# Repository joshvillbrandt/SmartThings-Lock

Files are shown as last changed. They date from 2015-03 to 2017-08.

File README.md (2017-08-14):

# SmartThings Lock

An Internet of Things door lock using an Arduino and the SmartThings platform.

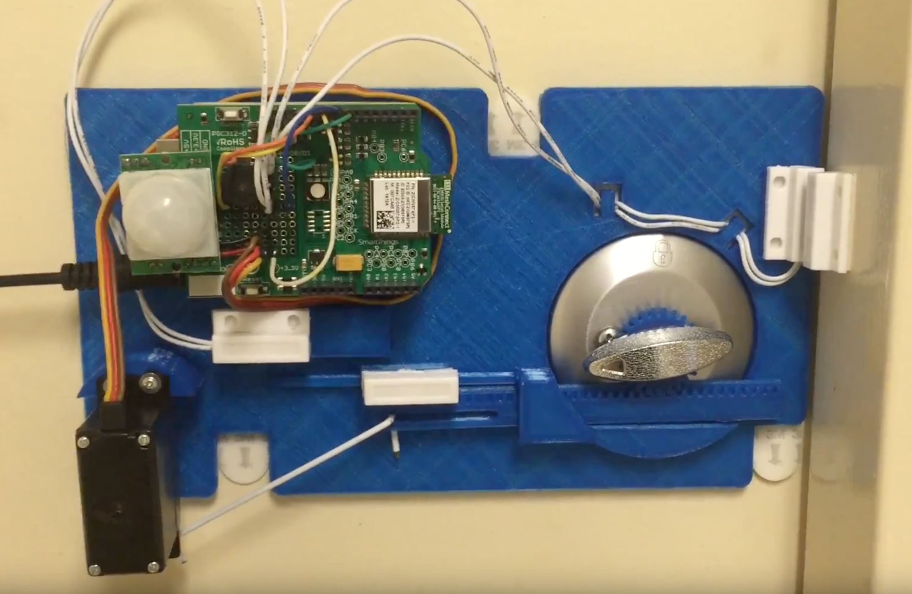
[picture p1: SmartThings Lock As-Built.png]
as-built screenshot


## Summary

This projects creates a network-connected door lock. The device uses two reed switches to report the open/closed status of the door and the locked/unlocked status of the lock. The door's lock may be engaged and disengaged via a servo. The locking mechanism works without inhibiting the door to be locked or unlocked via standard methods (using a key or by turning the thumb-turn.)

An Arduino Uno with a SmartThings ThingShield connects to the SmartThings hub with the help of the [ST_Anything](https://github.com/DanielOgorchock/ST_Anything) Arduino library.

## Bill of Materials

| Qty. | Item | Link |
| --- | --- | --- |
| 1 | Arduino Uno | http://www.amazon.com/IEIK-Board-ATmega328P-Cable-Arduino/dp/B00P2FX9WY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 |
| 1 | Arduino DC Power Adapter | http://www.amazon.com/Power-Adapter-Arduino-2-Flat-Pin-100CM/dp/B00CP1QLSC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 |
| 1 | SmartThings ThingShield | https://shop.smartthings.com/#!/products/smartthings-shield-arduino |
| 1 | Adafruit PIR Motion Sensor | http://www.amazon.com/gp/product/B00JOZTAC6/ref=oh_aui_detailpage_o00_s00?ie=UTF8&psc=1 |
| 2 | Magnetic Reed Switches | http://www.amazon.com/gp/product/B00HR8CT8E/ref=oh_aui_detailpage_o00_s00?ie=UTF8&psc=1 |
| 1 | Standard Servo | http://www.amazon.com/Hitec-31311S-HS-311-Standard-Universal/dp/B0006O3WVE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 |
| 1 | Piezo-electric buzzer | http://www.amazon.com/Terminals-Electronic-Continuous-Sound-Buzzer/dp/B00B0Q4KKO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 |
| 1 | 3D Printed SmartThings Lock Set | n/a |
| 1 | Wire Close Hanger | n/a |

## Electrical Schematic

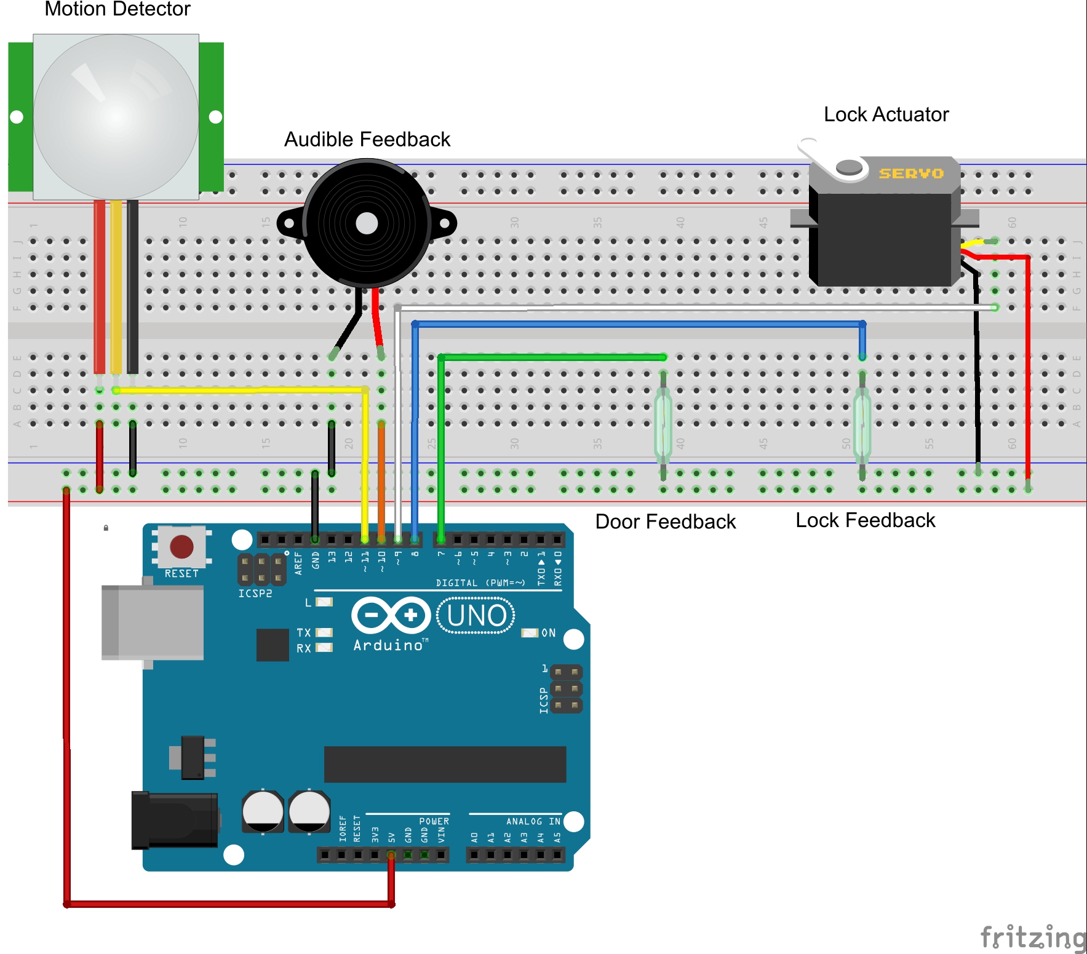
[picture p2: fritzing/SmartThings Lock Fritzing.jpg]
electrical screenshot


## Digital Model

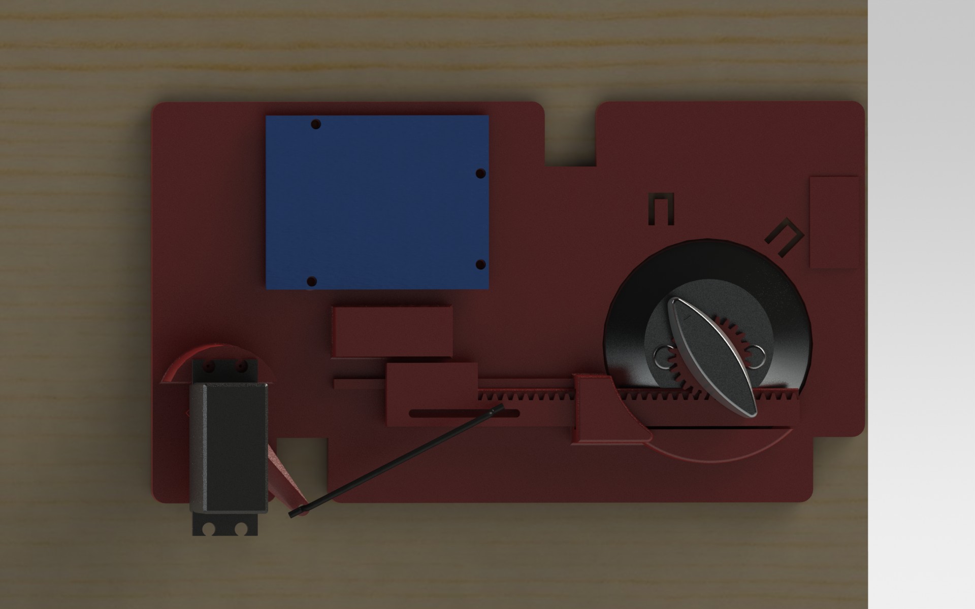
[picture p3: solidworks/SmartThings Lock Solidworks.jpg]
mechanical screenshot


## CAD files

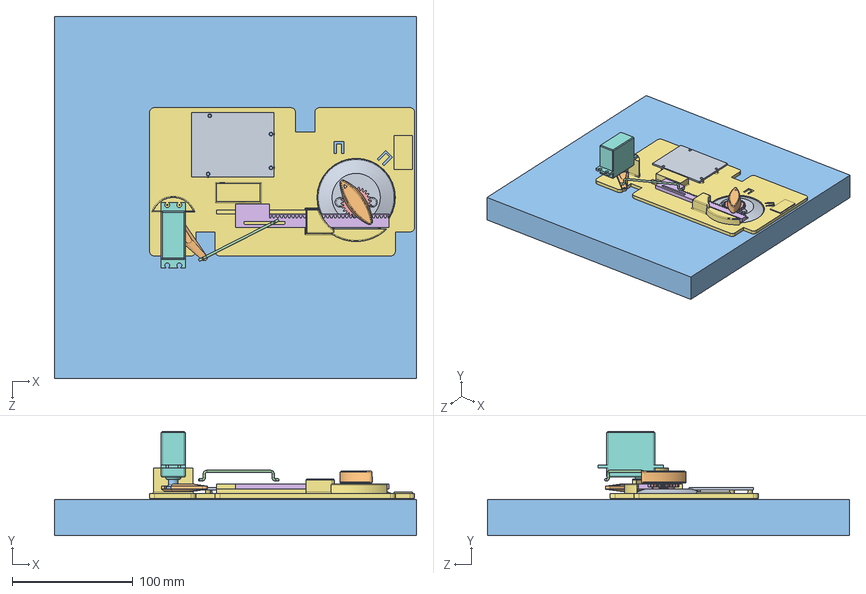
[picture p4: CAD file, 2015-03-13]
solidworks/SmartThings Lock.SLDASM
300.0 x 86.5 x 300.0 mm
Lock Body
Lock Thumb Turn
Door
Control Link
Control Gear
Control Runner
Base
Standard Servo
Arduino PCB
Control Arm Extender
Control Arm

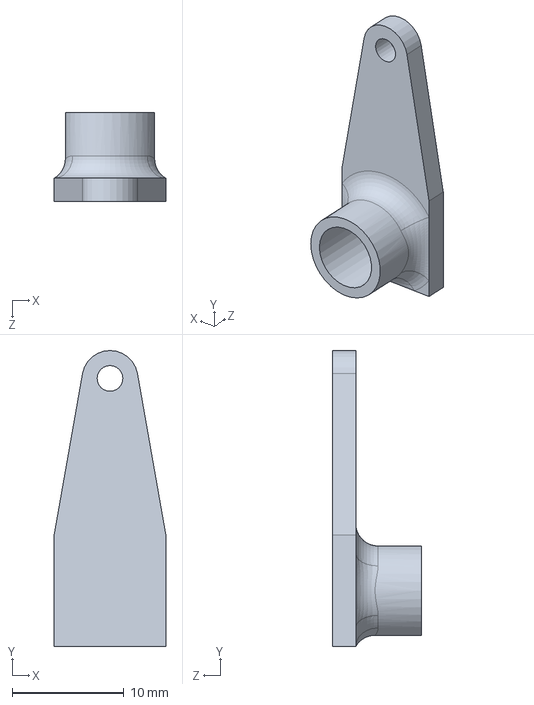
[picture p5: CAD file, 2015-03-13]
solidworks/Control Arm.SLDPRT
10.0 x 26.5 x 8.00 mm

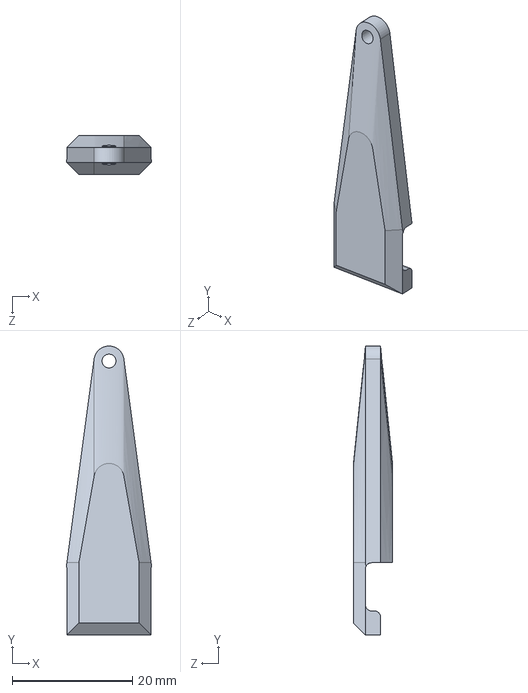
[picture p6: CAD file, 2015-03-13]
solidworks/Control Arm Extender.SLDPRT
14.2 x 48.0 x 6.50 mm

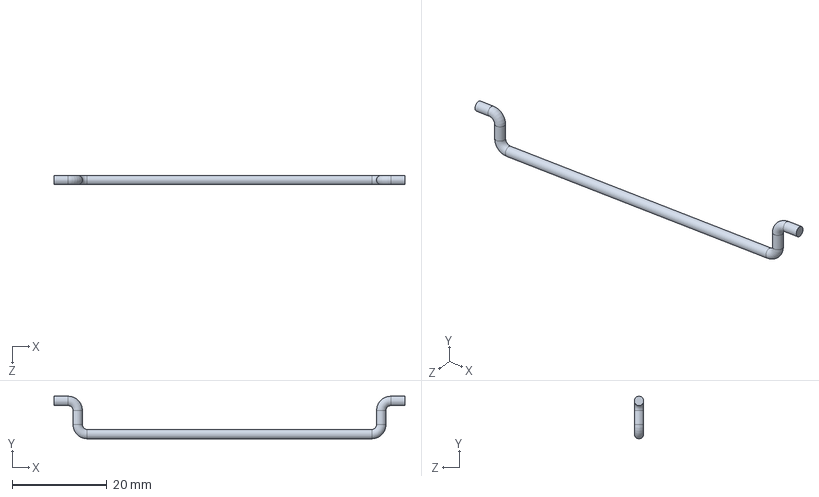
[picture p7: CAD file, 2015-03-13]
solidworks/Control Link.SLDPRT
74.0 x 9.00 x 2.00 mm

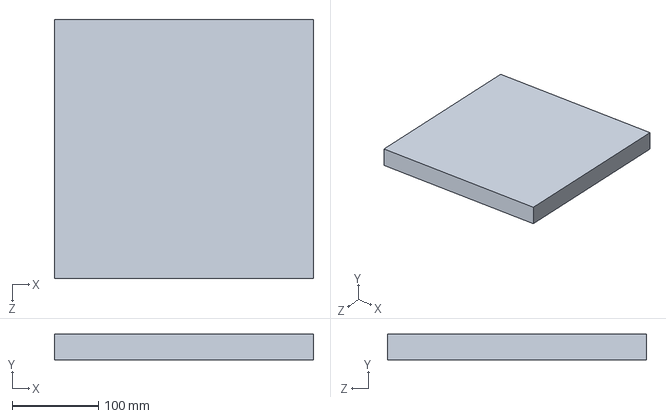
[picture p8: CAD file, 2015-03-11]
solidworks/Door.SLDPRT
300.0 x 30.0 x 300.0 mm

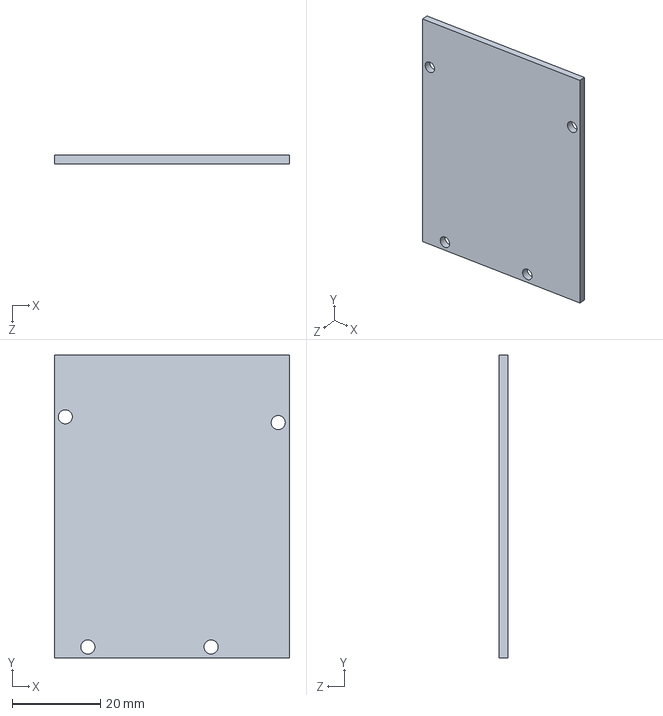
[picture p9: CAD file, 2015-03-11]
solidworks/Arduino PCB.SLDPRT
53.3 x 68.6 x 2.00 mm

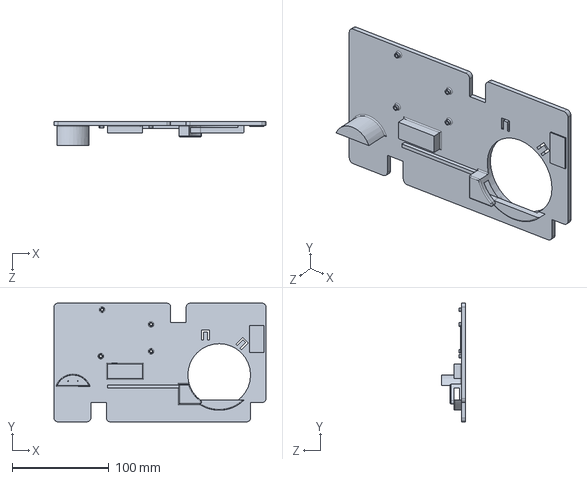
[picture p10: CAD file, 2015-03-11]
solidworks/Base.SLDPRT
219.7 x 123.0 x 25.0 mm

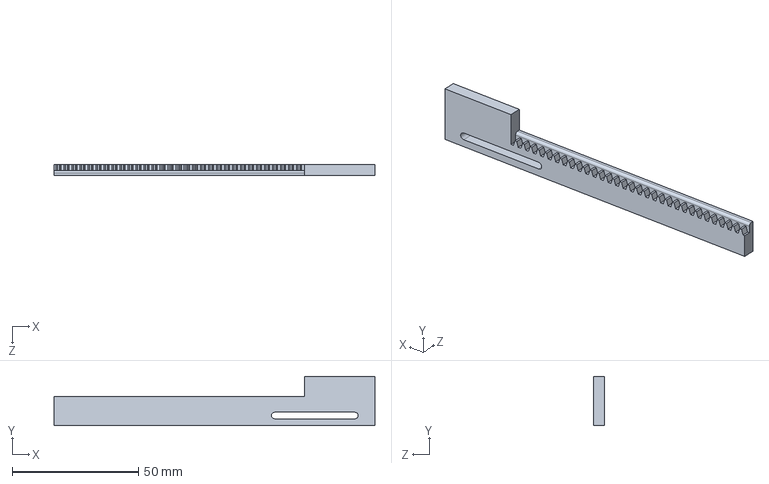
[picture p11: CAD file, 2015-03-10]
solidworks/Control Runner.SLDPRT
127.2 x 19.5 x 4.50 mm

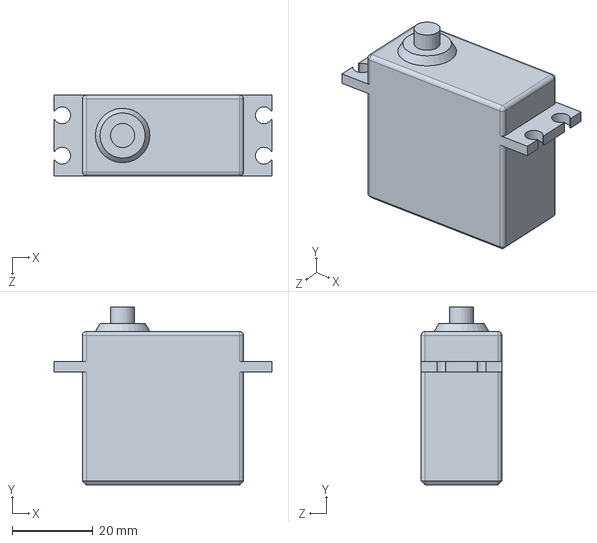
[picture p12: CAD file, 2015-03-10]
solidworks/Standard Servo.SLDPRT
54.0 x 44.0 x 20.0 mm

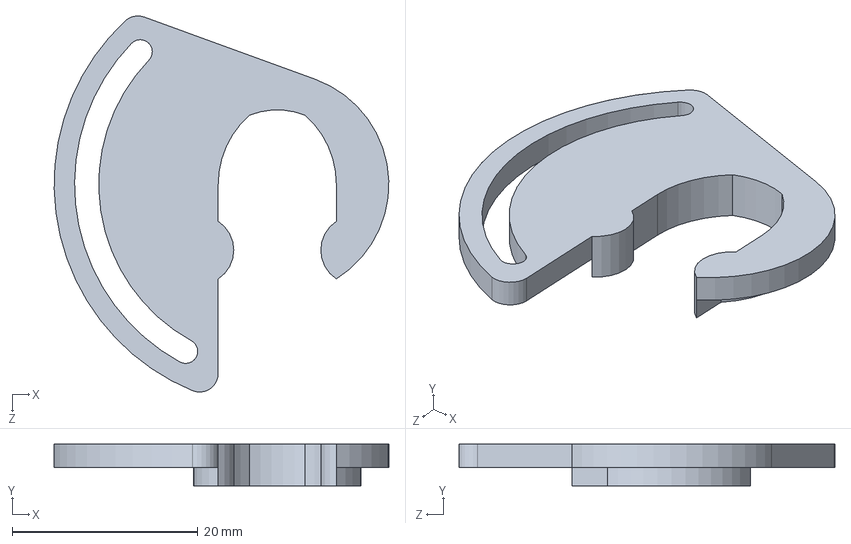
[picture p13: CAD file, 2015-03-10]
solidworks/Control Adapter.SLDPRT
36.0 x 4.50 x 40.4 mm

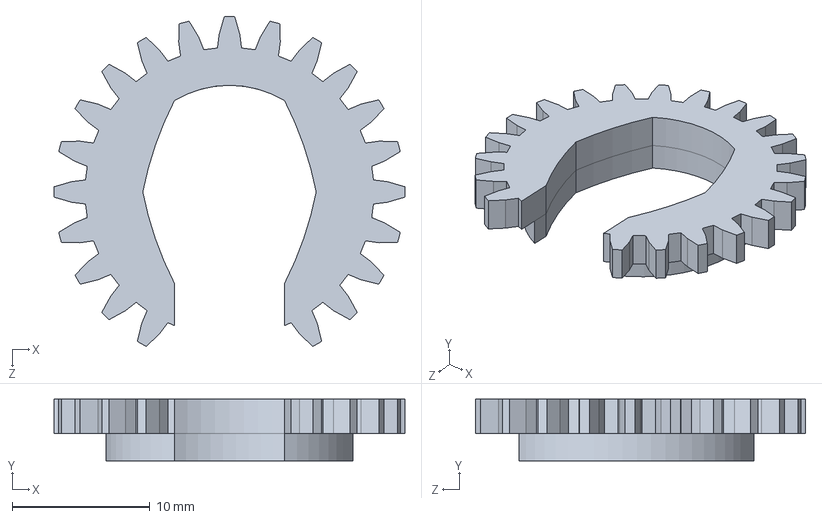
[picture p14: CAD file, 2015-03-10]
solidworks/Control Gear.SLDPRT
25.5 x 4.50 x 24.0 mm

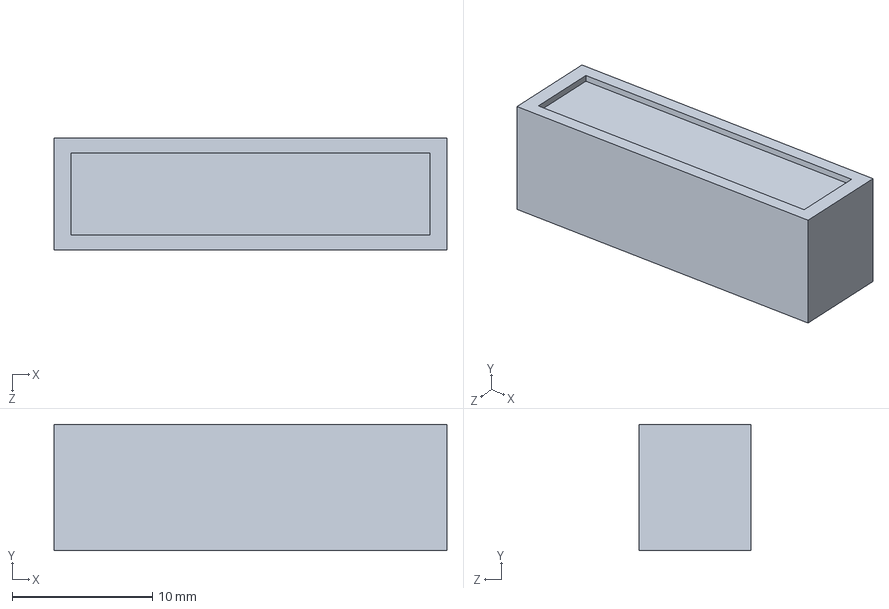
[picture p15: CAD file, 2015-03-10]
solidworks/Clipped Magnet.SLDPRT
28.0 x 9.00 x 8.00 mm

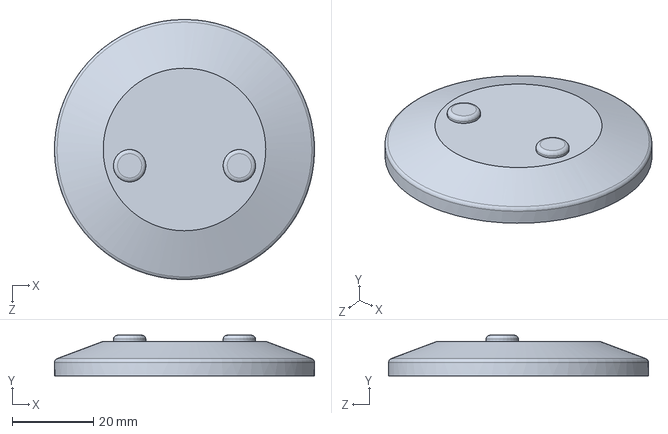
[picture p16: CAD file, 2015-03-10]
solidworks/Lock Body.SLDPRT
64.0 x 10.0 x 64.0 mm

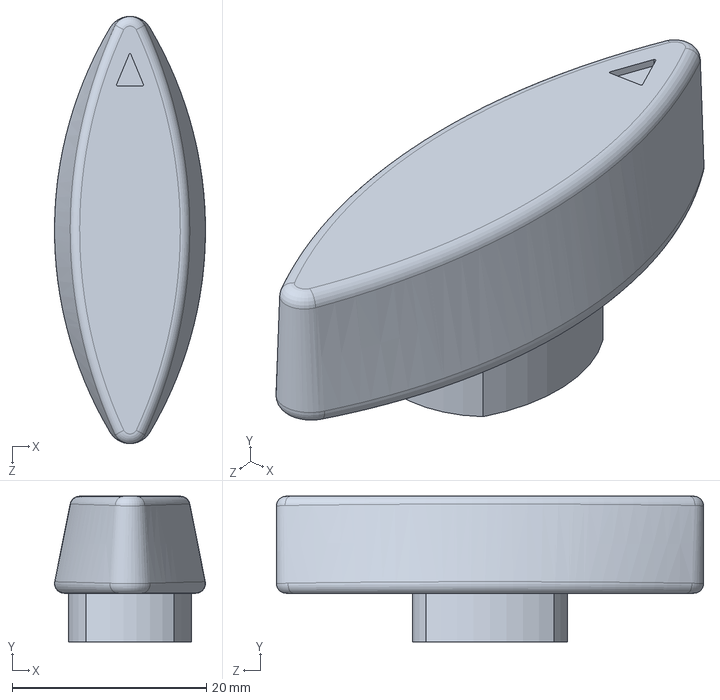
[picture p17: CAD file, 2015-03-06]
solidworks/Lock Thumb Turn.SLDPRT
15.6 x 15.0 x 44.0 mm

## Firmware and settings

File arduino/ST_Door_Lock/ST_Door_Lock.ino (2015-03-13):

//******************************************************************************************
//  File: ST_Door_Lock.ino
//  Authors: Josh Villbrandt
//
//  Change History:
//
//    Date        Who              What
//    ----        ---              ----
//    2015-03-13  Josh Villbrandt  Inital script]
//
//******************************************************************************************

//******************************************************************************************
// SmartThings Library for Arduino Shield
//******************************************************************************************
#include <SoftwareSerial.h> //Arduino UNO/Leonardo uses SoftwareSerial for the SmartThings Library
#include <SmartThings.h>    //Library to provide API to the SmartThings Shield
#include <RCSwitch.h>       //Library to provide support for RCSwitch devices
//******************************************************************************************
// ST_Anything Library
//******************************************************************************************
#include <Constants.h>       //Constants.h is designed to be modified by the end user to adjust behavior of the ST_Anything library
#include <Device.h>          //Generic Device Class, inherited by Sensor and Executor classes
#include <Sensor.h>          //Generic Sensor Class, typically provides data to ST Cloud (e.g. Temperature, Motion, etc...)
#include <InterruptSensor.h> //Generic Interrupt "Sensor" Class, waits for change of state on digital input
#include <PollingSensor.h>   //Generic Polling "Sensor" Class, polls Arduino pins periodically
#include <Everything.h>      //Master Brain of ST_Anything library that ties everything together and performs ST Shield communications

#include <IS_Motion.h>       //Implements an Interrupt Sensor (IS) to detect motion via a PIR sensor
#include <IS_Contact.h>      //Implements an Interrupt Sensor (IS) to monitor the status of a digital input pin
#include <IS_DoorControl.h> //Implements an Interrupt Sensor (IS) and Executor to monitor the status of a digital input pin and control a digital output pin

// pins
#define PIN_REED_DOOR     7
#define PIN_REED_LOCK     8
#define PIN_SERVO         9
#define PIN_BUZZER        10
#define PIN_MOTION        11

// buzzer
#define BUZZER_HIGH       294 // NOTE_D4
#define BUZZER_LOW        147 // NOTE_D3
#define BUZZER_DURATION   125 // ms

// servo
#include <Servo.h>
Servo servo;
#define SERVO_NEUTRAL     73  // deg
#define SERVO_LOCK        140 // deg
#define SERVO_UNLOCK      30  // deg
#define SERVO_DELAY       500 // ms

// timeouts
#define MOTION_TIMEOUT    1000 // ms
#define UNLOCK_TIMEOUT    5000 // ms
#define CLOSE_TIMEOUT     3000 // ms

// sensors
st::IS_Contact sensor1("door", PIN_REED_DOOR, LOW, true);
st::IS_Contact sensor2("lock", PIN_REED_LOCK, LOW, true);
st::IS_Motion sensor3("motion", PIN_MOTION, HIGH, false);
//st::EX_Switch executor1("sampleEX", PIN_sampleEX, LOW, true);

// state variables
int motionRaw = LOW;
int motion = LOW;
int doorClosedRaw = LOW;
int doorClosed = LOW;
int doorLockedRaw = HIGH;
int doorLocked = HIGH;
long motionTriggered = 0;
long doorUnlockTriggered = 0;
long doorCloseTriggered = 0;

void setup()
{
//  st::Everything::debug=true;
//  st::Executor::debug=true;
//  st::Device::debug=true;
//  st::PollingSensor::debug=true;
//  st::InterruptSensor::debug=true;
//  st::Everything::init();

//  st::Everything::addSensor(&sensor1);
//  st::Everything::addSensor(&sensor2);
//  st::Everything::addSensor(&sensor3);
  //st::Everything::addExecutor(&executor1);
//  st::Everything::initDevices();
  
  
  pinMode(PIN_REED_DOOR, INPUT_PULLUP);
  pinMode(PIN_REED_LOCK, INPUT_PULLUP);
  pinMode(PIN_MOTION, INPUT);
  
  pinMode(PIN_BUZZER, OUTPUT);
  servo.attach(PIN_SERVO);
  servo.write(SERVO_NEUTRAL);

  Serial.begin(9600);         // setup serial with a baud rate of 9600
  Serial.println("setup..");  // print out 'setup..' on start
}

void lock() {
  Serial.println("Locking...");
  
  // lock the door
  servo.write(SERVO_LOCK);
  tone(PIN_BUZZER, BUZZER_LOW);
  delay(BUZZER_DURATION);
  tone(PIN_BUZZER, BUZZER_HIGH, BUZZER_DURATION);
  delay(SERVO_DELAY - BUZZER_DURATION);
  
  // return servo to neutral position
  servo.write(SERVO_NEUTRAL);
  
  // this acts as a nice timeout before doing other actions
  delay(2 * SERVO_DELAY);
}

void unlock() {
  Serial.println("Unlocking...");
  
  // unlock the door
  servo.write(SERVO_UNLOCK);
  tone(PIN_BUZZER, BUZZER_HIGH);
  delay(BUZZER_DURATION);
  tone(PIN_BUZZER, BUZZER_LOW, BUZZER_DURATION);
  delay(SERVO_DELAY - BUZZER_DURATION);
  
  // return servo to neutral position
  servo.write(SERVO_NEUTRAL);
  
  // this acts as a nice timeout before doing other actions
  delay(2 * SERVO_DELAY);
}

void readSensors() {
  motionRaw = digitalRead(PIN_MOTION);
  doorClosedRaw = !digitalRead(PIN_REED_DOOR);
  doorLockedRaw = !digitalRead(PIN_REED_LOCK);
  
  // PIR timeout is too long - use rising edge of motionRaw to trigger motion,
  // but then motion back to LOW before motionRaw is at LOW
  if(motion == LOW && motionRaw == HIGH && motionTriggered == 0)
  {
    motion = HIGH;
    motionTriggered = millis();
  }
  if(motion == HIGH && millis() > (motionTriggered + MOTION_TIMEOUT))
  {
    motion = LOW;
  }
  if(motionRaw == LOW) {
    motionTriggered = 0;
  }
  
  // debounce lock state so that the lock does not fight us when we unlock the
  // door from outside when no motion is present (motion sensor is on the inside)
  if(doorLockedRaw == LOW)
  {
    // stagger door unlock propagation
    if(doorLocked == HIGH)
    {
      if(doorUnlockTriggered == 0)
      {
        doorUnlockTriggered = millis();
      }
      else if(millis() > (doorUnlockTriggered + UNLOCK_TIMEOUT))
      {
        doorLocked = LOW;
      }
    }
  }
  else
  {
    // immediately notify that door is locked
    doorLocked = HIGH;
    doorUnlockTriggered = 0;
  }
  
  // don't try to lock the door while the door is still closing and give
  // the person a chance to re-open the door after closing before locking
  if(doorClosedRaw == HIGH)
  {
    // stagger door close propagation
    if(doorClosed == LOW)
    {
      if(doorCloseTriggered == 0)
      {
        doorCloseTriggered = millis();
      }
      else if(millis() > (doorCloseTriggered + CLOSE_TIMEOUT))
      {
        doorClosed = HIGH;
      }
    }
  }
  else
  {
    // immediately notify that door is locked
    doorClosed = LOW;
    doorCloseTriggered = 0;
  }
  
  
  // debug
  Serial.print("motion: ");
  Serial.print(motion);
  Serial.print(", doorClosed: ");
  Serial.print(doorClosed);
  Serial.print(", doorLocked: ");
  Serial.print(doorLocked);
  Serial.println();
}

void loop()
{
//  st::Everything::run();
  
  // read in sensor values
  readSensors();
  
  // predefined automated responses
  if(motion) {
//    st::Everything::SmartThing.shieldSetLED(0, 1, 1); // cyan
    
    // unlock the door if motion is detected
    if(doorClosed && doorLocked) {
      unlock();
    }
  }
  else {
    
    // lock the door when no motion is detected
    if(doorClosed && !doorLocked) {
      lock();
    }
  }
}

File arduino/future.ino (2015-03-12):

//*****************************************************************************
/// @file
/// @brief
///   Arduino SmartThings Door Lock - Josh Villbrandt, March 2015
//*****************************************************************************

// includes
#include <SoftwareSerial.h>
#include <SmartThings.h>

// pins
#define PIN_THING_TX    2
#define PIN_THING_RX    3
#define PIN_REED_DOOR   7
#define PIN_REED_LOCK   8
#define PIN_SERVO       9
#define PIN_BUZZER      10
#define PIN_MOTION      11

// init SmartThings
SmartThingsCallout_t messageCallout;
SmartThings smartthing(PIN_THING_RX, PIN_THING_TX, messageCallout);  // constructor

// start variables
bool isDebugEnabled = true;
int motion = LOW;
int doorOpen = HIGH;
int doorLocked = HIGH;

void setup()
{
  // setup hardware pins
  pinMode(ledPin, OUTPUT);
  pinMode(ledPin, OUTPUT);
  pinMode(ledPin, OUTPUT);

  // setup debug serial port
  if (isDebugEnabled)
  {
    Serial.begin(9600);
    Serial.println("Door Lock - setup complete");
  }
}

void loop()
{
  // read in sensor values
  readSensors();

  // perform automated responses
  automatedResponses();

  // run smartthing logic
  smartthing.run();
}

void readSensors()
{
  motion = digitalRead(PIN_MOTION);
  doorOpen = digitalRead(PIN_REED_DOOR);
  doorLocked = digitalRead(PIN_REED_LOCK);
}

void lock()
{
  // todo
}

void unlock()
{
  // todo
}

void automatedResponses()
{
  // turn on RGB LED if motion is detected

}

void messageCallout(String message)
{
  // if debug is enabled print out the received message
  if (isDebugEnabled)
  {
    Serial.print("Received message: '");
    Serial.print(message);
    Serial.println("' ");
  }

  // perform actions
  if (message.equals("lock")) lock();
  else if (message.equals("unlock")) unlock();
}

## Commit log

2015-03-06 Add lock model
    [Lock Body.SLDPRT, Lock Thumb Turn.SLDPRT, SmartThings Lock.SLDASM]
2015-03-06 Add control adapter and control link
    [Control Adapter.SLDPRT, Control Link.SLDPRT, Door.SLDPRT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]
2015-03-06 Add servo
    [Control Arm.SLDPRT, SmartThings Lock.SLDASM, Standard Servo.SLDPRT]
2015-03-07 Add Fritzing schematic
    [SmartThings Lock.fzz]
2015-03-07 Update control adapter
    [Control Adapter.SLDPRT, SmartThings Lock.SLDASM]
2015-03-10 Change pins as to not conflict with the SmartThings arduino library
    [SmartThings Lock.fzz]
2015-03-10 Switch to gear and runner setup
    [Base.SLDPRT, Clipped Magnet.SLDPRT, Control Adapter.SLDPRT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]
2015-03-10 Mount servo
    [Base.SLDPRT, Control Link.SLDPRT, Control Runner.SLDPRT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]
2015-03-10 Update CAD screenshot
2015-03-11 Complete base model
    [Arduino PCB.SLDPRT, Base.SLDPRT, SmartThings Lock.SLDASM]
2015-03-12 Add Arduino sketch to send lock, door, and motion status
2015-03-12 Complete bill of materials
2015-03-13 Auto lock and unlock with servo
2015-03-13 Update control arm model
    [Control Arm Extender.SLDPRT, Control Arm.SLDPRT, Control Link.SLDPRT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]
